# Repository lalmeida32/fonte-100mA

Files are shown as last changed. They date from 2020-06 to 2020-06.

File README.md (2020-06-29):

# Projeto: Fonte-100mA — TRABALHO 01

### Grupo 19, Integrantes:

* Adrio O. Alves (*11796830*)
* Eduardo V. B. Rossi (*10716887*)
* Felipi Y. Santos (*11917292*)
* Lucas F. de Almeida (*1162063*)

**Docente**: Eduardo do Valle Simões
**Curso**: SSC0180 - Eletrônica para Computação

**Bacharelado em Ciências da Computação — 2020**
**Instituto de Ciências Matemáticas e de Computação**
**Universidade de São Paulo**

---

# Introdução

	O projeto de trabalho 1 tem como objetivo a construção de uma fonte de alimentação genérica que precisa  fornecer corrente de até 100mA (*miliampères*) e uma tensão entre 3V e 12V. O projeto conta com um diagrama contendo os componentes eletrônicos escolhidos para construção da fonte, juntamente com o preço de cada um. Além disso, o projeto da fonte foi modelado em duas ferramentas de construção de circuitos: Falstad e EAGLE, e também um vídeo apresentando uma visão geral.

 # O repositório

* **estudo-do-projeto**

  * *Estudos.md*: Esse markdown dá informações do que cada componente eletrônico usado na fonte é, como ele é usado na fonte, isto é, seu papel.

  * **imagens**: fotos de peças/dependência do Estudos.md

  * *Dimensionamento.md*: relação de gastos e links para cada componente

* **arquivos-circuitos**

  * **FONTE**: arquivos do projeto no Eagle (contém esquemático e PCB)
  * *circuit-20200628-2337.circuitjs.txt*: um export do circuito feito no Falstad.
  * **EAGLE:** diretório contendo os arquivos do projeto no EAGLE
  * *eagle.jpg*: um export do projeto esquemático no EAGLE
  * *pcb.png*: um export do projeto em PCB no EAGLE
  * *circuito.png*: foto do circuito no falstad

# Diagrama da Fonte

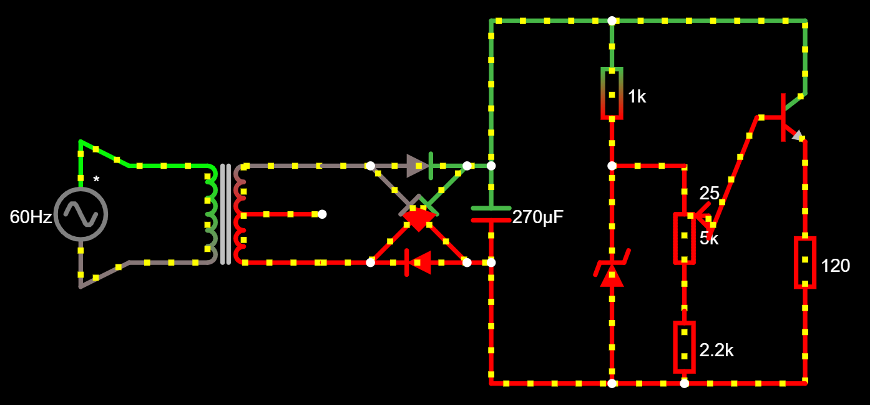
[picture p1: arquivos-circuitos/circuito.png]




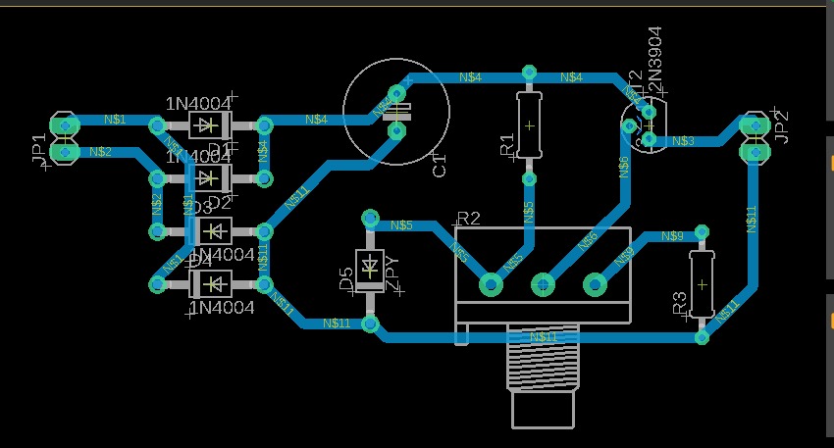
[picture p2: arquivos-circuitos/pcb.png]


# Relação componente/valores

**Obs**.: Desconsideramos o frete pois os preços de entrega encontram-se mais elevados durante o período da Pandemia (COVID-19). 

| Componente | Links | Quantidade | Preço resultante |
| --- | --- | --- | --- |
| **Transformador** 10+10 bivolt 800mA | https://produto.mercadolivre.com.br/MLB-1304934993-transformador-trafo-1010v-800ma-bivolt-eletrnica-_JM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 | x1 | R$ 30,00 |
| **Diodos da ponte retificadora** (1n4007) | https://www.robocore.net/loja/itens-eletronicos/diodo-1n4007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 | x4 | R$ 0,18 x 4 =  0,72 |
| **Capacitor** eletrolítico 270uF / 50V | https://produto.mercadolivre.com.br/MLB-1539705638-cap-eletrolitico-270uf-50v-kit-c-50-pcs-_JM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 | x1 | R$ 15,50 |
| **Diodo Zener** (BZX55C 13V/0,5W) | https://www.baudaeletronica.com.br/diodo-zener-bzx55c-13v-0-5w.html | x1 | R$ 0,09 |
| **Transistor NPN** (BC337) | https://www.robocore.net/loja/itens-eletronicos/transistor-npn-bc337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 | x1 | R$ 1,20 |
| **Resistor** (1kΩ) | https://www.robocore.net/loja/itens-eletronicos/resistor-1k-pacote-com-10-unidades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 | x1 | R$ 0,75 |
| **Resistor** (2.2kΩ) | https://www.eletroinfocia.com.br/resistor-1-4w-2k2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 | x1 | R$ 0,10 |
| **Potenciômetro** | https://www.engetronic-sc.com.br/produtos/ver/321/potenciometro-linear-5k-l15---eixo-estriado-tracking-google-shopping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 | x1 | R$ 1,35 |
| **TOTAL:** | | 11 | R$ 49,72 |

# Sobre os componentes não encontrados no EAGLE

	Como o EAGLE não possui todos os componentes que foram utilizados na fonte, tivemos de utilizar componentes com funcionalidade e dimensões iguais no lugar.

# Links

* Vídeo explicativo da fonte: https://youtu.be/iQQ3Y2TPxfM
* Falstad (cópia em arquivos-circuitos): https://tinyurl.com/y8z7htxh
* Eagle (esquemático): https://imgur.com/a/H5OCaSa
* Eagle (PCB): https://imgur.com/a/zWWUykP

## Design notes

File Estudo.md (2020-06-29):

# Estudo do Projeto

Fonte de 100mA

## Introdução

Neste documento se encontram as informações adquiridas para a montagem da fonte.

## Componentes

### Resistor

O resistor é um dispositivo elétrico que consome corrente elétrica. É utilizado principalmente para limitar a corrente elétrica em um circuito e para converter energia elétrica em energia térmica.

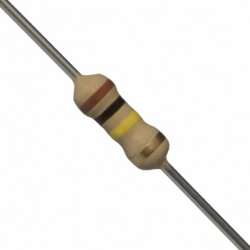
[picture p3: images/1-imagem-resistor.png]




Uma equação importante ao trabalhar com resistores é U = R ∙ i (Primeira Lei de Ohm), em que U é a diferença de potencial (em Volts), R é a resistência (em Ohms) e i é a corrente elétrica (em Amperes). A corrente no circuito varia de acordo com a resistência e a tensão.

    Primeira Lei de Ohm: U = R ∙ i

Outra equação importante para entender a grandeza “resistência elétrica”, é a Segunda Lei de Ohm. Na verdade, até um fio apresenta resistência, mas em circuitos simples não é necessário considerá-la.

    Segunda Lei de Ohm: R = (ρ ∙ L)/A

Nesse caso, ρ é uma constante associada ao material, (resistividade do material) L é o comprimento do fio e A é a área da seção transversal do fio.

Resistores combinados em série e em paralelo podem ser substituídos por um resistor equivalente. Caso os resistores sejam ligados em série, a nova resistência será igual à soma das resistências. Em paralelo, o inverso da nova resistência será igual à soma do inverso das resistências.

    Associação em série: Req = R1 + R2 + ⋯

    Associação em paralelo: 1/Req = 1/R1 + 1/R2 + ⋯

É importante notar o que acontece com a tensão e a corrente em circuitos elétricos em série e em paralelo.

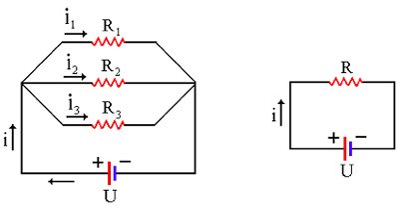
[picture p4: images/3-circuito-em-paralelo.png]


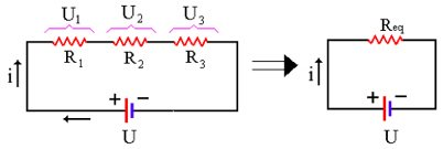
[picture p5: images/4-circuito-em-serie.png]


O circuito em paralelo divide a corrente (nesse caso, i1 + i2 + i3 = i), mas a tensão é a mesma em todos os resistores. Já no circuito em série, a tensão que é dividida (com U1 + U2 + U3 = U), sendo que a corrente que passa por cada um dos resistores é a mesma. O que descreve isso mais formalmente são as Leis de Kirchhoff.

Por esse motivo, para medir tensão, colocamos o voltímetro em paralelo, e para medir corrente, colocamos o amperímetro em série com o circuito.

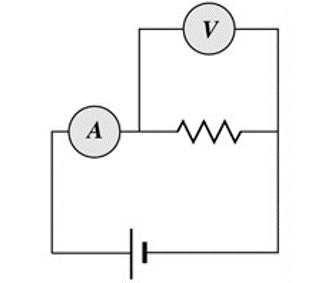
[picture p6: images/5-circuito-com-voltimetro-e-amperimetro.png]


Além disso, cada resistor consome energia de acordo com o tempo. Para medir isso, basta usar a potência, em watts. (1W = 1 J/s)

    Potência no resistor: P = U ∙ i

Para identificar quanto vale a resistência de um resistor segundo as faixas de cores que estão nele, basta utilizar a seguinte tabela:

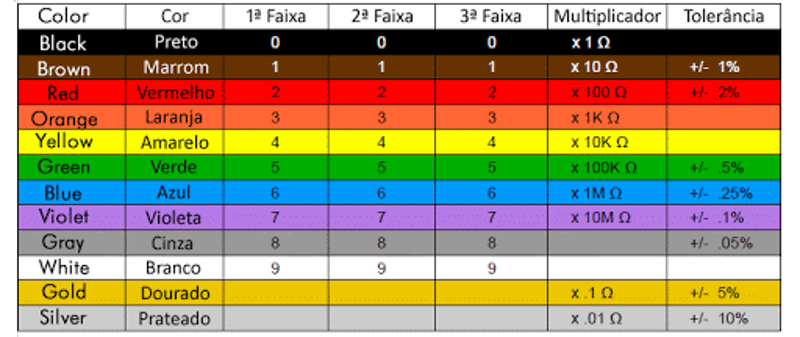
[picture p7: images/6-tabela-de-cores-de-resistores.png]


### Capacitor

O capacitor é um componente que armazena cargas elétricas.

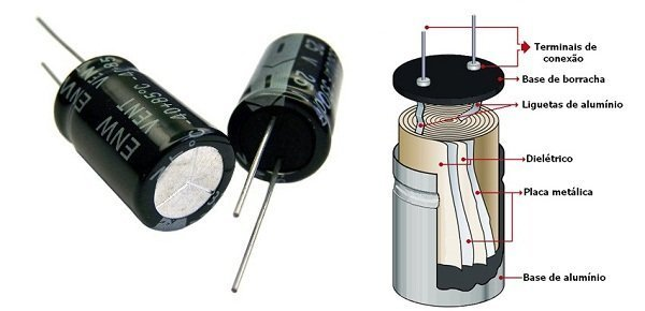
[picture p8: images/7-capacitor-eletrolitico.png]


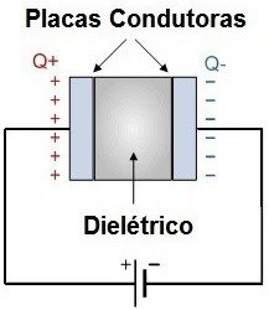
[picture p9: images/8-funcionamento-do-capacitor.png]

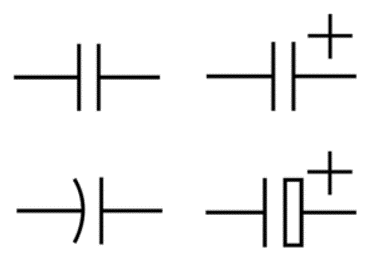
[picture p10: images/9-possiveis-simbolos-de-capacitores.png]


*Observação: Alguns tipos de capacitores são polarizados e outros não*

Em um capacitor, há um material isolante elétrico entre duas placas condutoras. Ao ligar o capacitor em um gerador de tensão, os elétrons se acumularão em uma das placas, gerando uma diferença de potencial entre seus terminais.

Em determinado momento, a diferença de potencial no capacitor será quase igual à diferença de potencial no gerador de tensão, e então o capacitor será carregado muito lentamente.

Uma vez carregado, o capacitor serve de gerador de tensão e pode ser descarregado em um circuito.

Para medir a capacidade de armazenamento de um capacitor, utiliza-se a grandeza escalar “capacitância”. Quanto maior a capacitância, maior a capacidade de armazenamento. A capacitância C (em farads) está associada com a área das placas condutoras S (em metros quadrados), a distância entre elas d (em metros) e a constante dielétrica ε (em farads por metro) pela seguinte relação:

    C = ε S/d

Há também outro jeito de calcular a capacitância:

    C = q/ΔV

Em que C é a capacitância, em farads, q é a carga elétrica armazenada, em coulombs, e V é a diferença de potencial, em volts.

Sendo assim, temos que 1F = 1C/V.

Ao associar capacitores em série ou paralelo, podemos obter um capacitor com capacitância equivalente aplicando as seguintes fórmulas:

    Associação em série: 1/Ceq = 1/C1 + 1/C2 + ⋯

    Associação em paralelo: Ceq = C1 + C2 + ⋯

É importante também estudar o circuito RC. (Resistor e Capacitor)

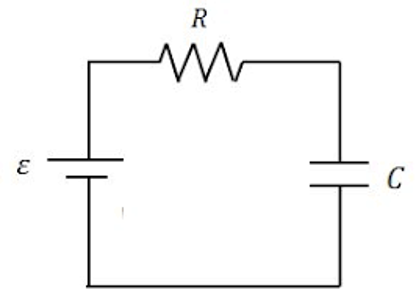
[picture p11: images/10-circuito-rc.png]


Nesse circuito, o capacitor levará um tempo para ser carregado. Estes gráficos descrevem o que acontece no circuito RC.

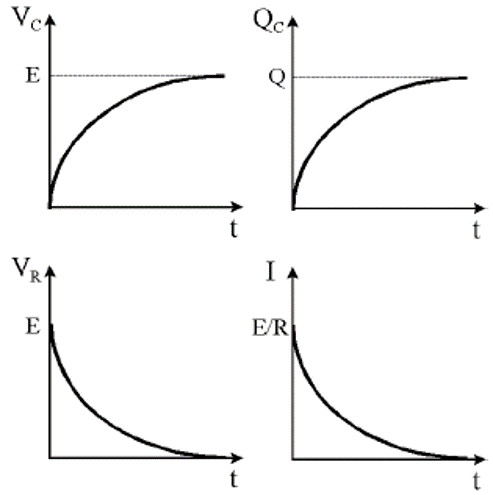
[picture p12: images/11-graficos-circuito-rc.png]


Vc é a tensão no capacitor, Qc é a carga no capacitor, Vr é a tensão no resistor e I é a corrente no circuito. (o resistor e o capacitor estão em série e a mesma corrente passa por eles)

Nesse circuito, o tempo que leva para o capacitor carregar é diretamente proporcional à capacitância e à resistência. (quanto maior a resistência/capacitância, maior o tempo que leva)

A tensão elétrica no gerador de tensão define qual será a tensão máxima que o capacitor poderá atingir.

*Observação: Ao descarregar o capacitor em um resistor, os gráficos são semelhantes, mas a tensão e a carga no capacitor diminuem ao invés de aumentar.*

### Diodo

O diodo é um componente que só deixa passar corrente em um sentido.

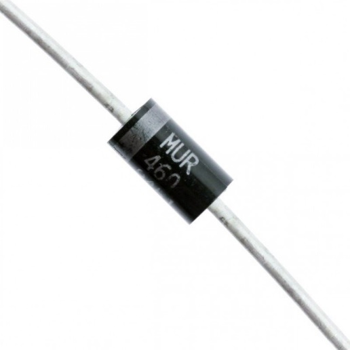
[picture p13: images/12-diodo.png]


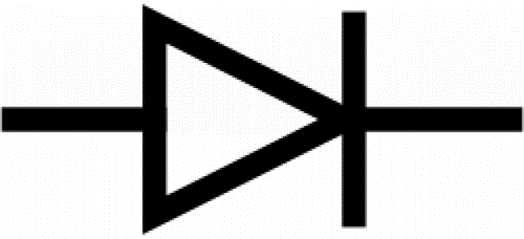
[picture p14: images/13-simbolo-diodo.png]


O sentido que o diodo permite a corrente passar é o sentido da seta em seu símbolo.

Em um diodo real, se determina esse sentido através da faixa cinza que há nele. Chamamos o terminal mais próximo da faixa cinza de cátodo (negativo) e o terminal mais longe de ânodo (positivo).



Caso o diodo seja ligado diretamente (negativo no cátodo e positivo no ânodo), a corrente fluirá como se o diodo fosse uma chave fechada. Caso ele seja conectado inversamente (positivo no cátodo e negativo no ânodo), o diodo se comportará como uma chave aberta.

Na realidade, o diodo conectado diretamente funciona como chave fechada a partir de determinada tensão. Para entender melhor como isso funciona, veja a figura abaixo.

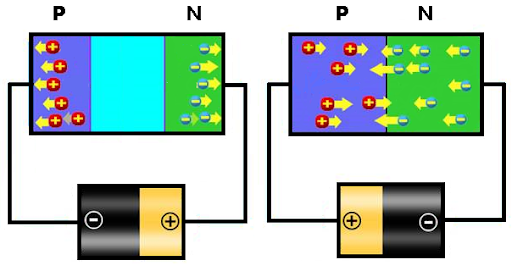
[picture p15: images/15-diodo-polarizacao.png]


A região do meio de um diodo é chamada de barreira de potencial (ou camada de depleção). Ela separa o cátodo e o ânodo de um diodo. Quando um diodo é ligado inversamente, essa barreira aumenta pois as cargas positivas são atraídas para o polo negativo da pilha e as cargas negativas, para o polo positivo da pilha. Já se o diodo é ligado diretamente, ao aumentar a tensão, a barreira de potencial fica cada vez menor até que, em certo momento, ela desaparece e o diodo passa a funcionar como um fio.

Dessa forma, o diodo causa uma queda de tensão no circuito. No exemplo abaixo, apesar da fonte de tensão fornecer 10V, a tensão no resistor será em torno de 9,2V, já que se trata de um diodo de silício (o material influencia na tensão necessária para "quebrar" a barreira de potencial).

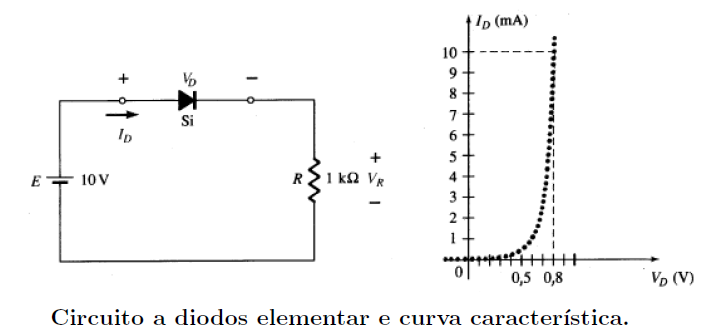
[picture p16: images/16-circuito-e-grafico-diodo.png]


*Observação: é comum dizer que o diodo de silício causa uma queda de tensão de aproximadamente 0,7V. Aqui neste documento está escrito como se causasse 0,8V por conta do gráfico presente na imagem*

O significado da sigla LED é *Light Emissor Diode*, ou seja, se trata de um diodo também. LEDs costumam causar uma queda de tensão maior que 0,7V, geralmente multímetros possuem uma função para calcular essa tensão.

Há coisas como corrente e tensão máximas que um diodo pode suportar. Isso depende do diodo e esse tipo de informação pode ser encontrada no datasheet.

### Diodo Zener

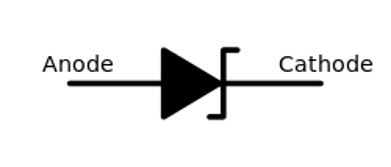
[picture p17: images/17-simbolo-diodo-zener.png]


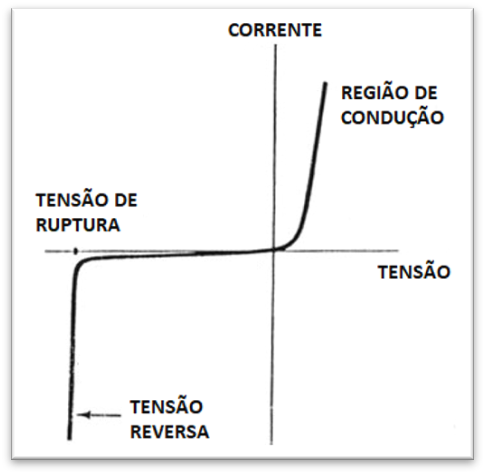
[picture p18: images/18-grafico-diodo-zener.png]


O diodo zener é como um diodo normal, porem a partir de certa tensão ele passa a ser um curto circuito, essa é a TENSÃO ZENER. Se a tensão no diodo zener for menor que a tensão zener ele não conduz, assim como os diodos convencionais. Se a tensão for maior que a tensão zener, o diodo zener mesmo estando contrario ao circuito vai conduzir.

    Uin < |Vzener|, Uout = Uin

    Uin > |Vzener|, Uout = Vzener

O diodo zener tem uma corrente máxima suportável, e isso é delimitado de acordo com a potencia do componente, caso a potência do circuito seja ultrapassada, o diodo pode se danificar.

    Izmax = Pz/Vz

    Izmin = Izmax ∙ 0,10

    Rzmin = (Vcc - Vz)/Izmax

    Rzmax = (Vcc - Vz)/Izmin

*Rz: Resistor limitador de corrente*

Esse diodo é muito bom para retificar a onda de tensão, principalmente quando se deseja estabelecer uma tensão continua. Nesse ciruito, o zener pode ser útil, porque ele controla a tensão, cortando-a em apenas um valor. Isso acontece porque ele mantém o valor de tensão máxima em seus terminais caso esteja conduzindo reversamente.

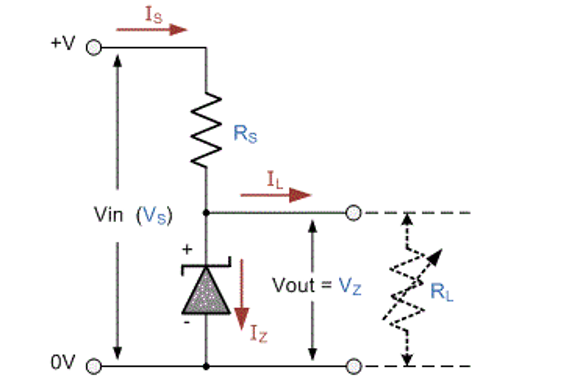
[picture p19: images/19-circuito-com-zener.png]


Esse é um simples circuito limitador de tensão usando zener. Vout sempre será Vz (tensão zener) na carga sempre que Vin > Vz, já que o diodo zener irá limitar.

### Transformadores
O transformador modifica os níveis de tensão e corrente elétrica, mantendo a potência constante.
Como a potência se mantém constante, ao usarmos o transformador para diminuir a tensão, a corrente do nosso circuito vai aumentar.

    P1 = P2 <=> V1 . I1 = V2 . I2

Estrutura:

Enrolamento:  O enrolamento de um transformador é formado de várias bobinas (os transformadores mais comuns usam duas) que em geral são feitas de cobre. Quando a corrente passa pela bobina forma um campo magnético que produz uma tensão elétrica nas extremidades desse enrolamento. A alteração na corrente presente na bobina do circuito primário altera o fluxo magnético nesse circuito e também na bobina do circuito secundário.

Núcleo: responsável por transferir a corrente do enrolamento primário para o enrolamento secundário. A mudança no fluxo magnético na bobina secundária induz uma tensão elétrica na bobina secundária

O transformador altera a tensão através de duas bobinas, seguindo uma proporção de uma bobina para a outra. Ex: se tivermos 100 voltas em uma e 10 voltas na outra, a tensão será transformada na proporção de 10 para 1, ou seja, se tivermos 100V na entrada, teremos 10V na saída.

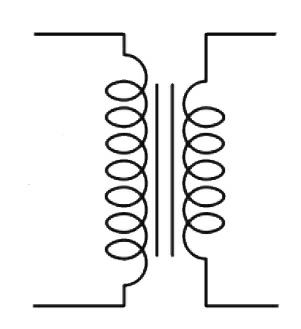
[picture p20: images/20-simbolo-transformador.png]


*Observação: damos o nome de primário o enrolamento da esquerda e secundário o da direita*

Os valores analisados em um transformador são relativos à tensão eficaz. Por exemplo, a tensão eficaz V1 é transformada na tensão eficaz V2.
Para calcular a tensão eficaz, basta dividir a tensão de pico por √2.

As tomadas residenciais geralmente fornecem de 110V a 127V ou de 220V a 254V de tensão eficaz.

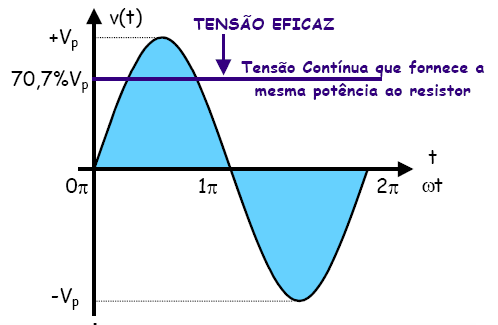
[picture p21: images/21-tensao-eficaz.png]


Há transformadores com derivação central. Segue na imagem abaixo um exemplo de um.

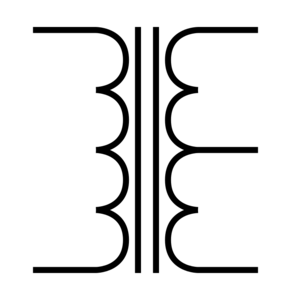
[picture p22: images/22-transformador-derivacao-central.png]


Se o transformador for 12V + 12V, por exemplo, significa que entre um dos terminais laterais e o terminal do meio, há 12V. Dessa forma, ao medir a tensão entre os terminais laterais, o resultado deve ser 24V (tensão eficaz)

Além disso, transformadores reais possuem rendimento, pois dissipam calor. Por exemplo, um transformador com 90% de rendimento, significa que a potência no secundário é 90% da potência no primário. Transformadores bons possuem mais que 90% de rendimento.

Geralmente transformadores são projetados também com um fio a mais no primário para tornar possível a escolha entre 127V ou 220V.

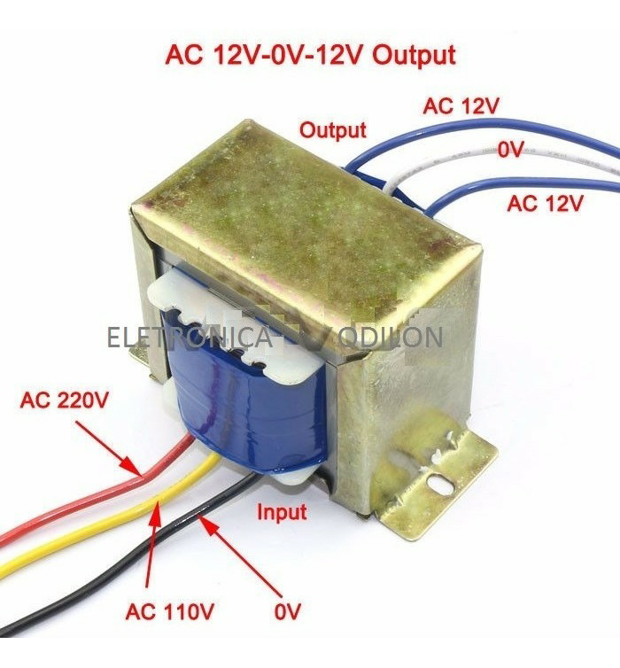
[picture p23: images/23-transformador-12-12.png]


Este é um exemplo de transformador real. Nesse caso, o fio de 127V está próximo ao meio da bobina, como na derivação central, mas não se encontra exatamente no meio.

Uma chave seletora pode ajudar na passagem de 127V para 220V e vice-versa.

### Potenciômetro

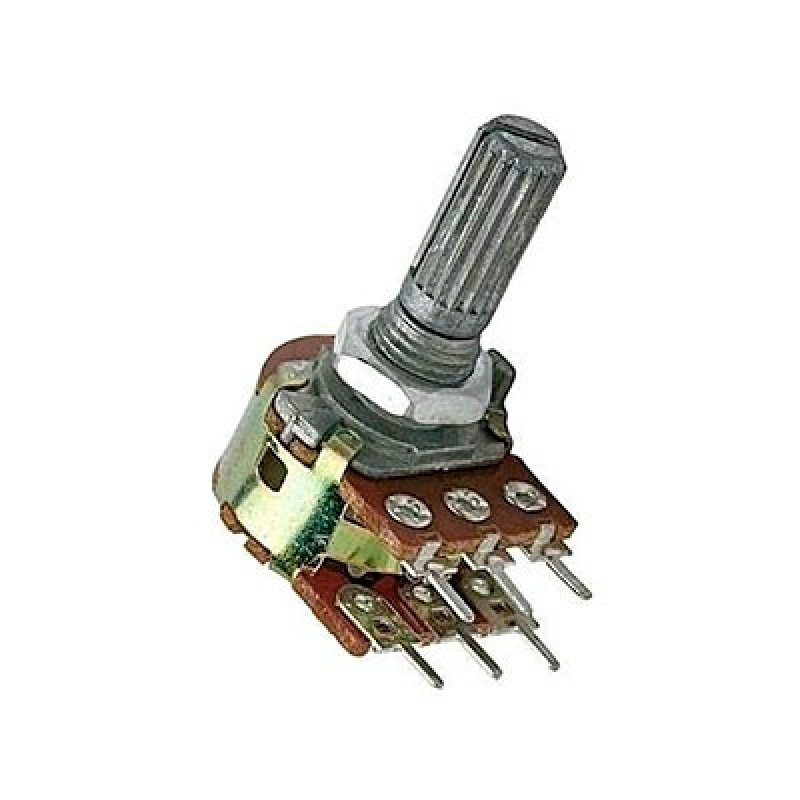
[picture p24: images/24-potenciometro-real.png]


Um potenciômetro é como se fosse um conjunto de duas resistências em que é possível regular manualmente a proporção em que cada uma delas vai receber da resistência total. Segue duas imagens para melhor entendimento.

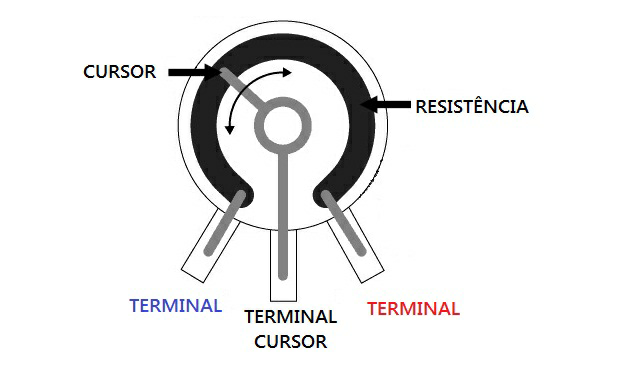
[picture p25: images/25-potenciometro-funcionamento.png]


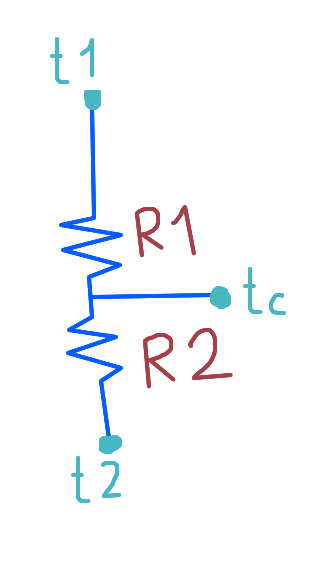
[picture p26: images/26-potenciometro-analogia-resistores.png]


O cursor pode ser ajustado manualmente. Ele determina qual porção da resistência total do potenciômetro o R1 e o R2 vão ter. Note que R1 + R2 deve ser igual à resistência do potenciômetro.

Note também que tc é o terminal do cursor, enquanto t1 e t2 são os terminais de R1 e de R2, respectivamente.

Suponha um potenciômetro de 100Ω. R1 + R2 sempre será 100Ω, mas o valor de R1 e de R2 pode ser regulado pelo cursor. Por exemplo, ao aproximar o cursor de t1, R1 se aproxima de 0Ω e R2 se aproxima de 100Ω. Ao aproximar de t2, R2 se aproxima de 0Ω enquanto R1 se aproxima de 100Ω. Há infinitos valores intermediários, como R1 = 67,3Ω e R2 = 32,7Ω.

Potenciômetros podem ser encontrados, por exemplo, em caixas de som no regulador de volume.

### Transistor NPN

O transistor TBJ NPN, é um componente que funciona como uma válvula/interruptores de tensão em um circuito, ou também, ele funciona ou barrando, ou amplificando a corrente elétrica. Seu funcionamento depende de 3 terminais, base, coletor e emissor. A corrente a ser controlada é a Ic := corrente no coletor, ou seja, é a corrente que passa do coletor ao emissor.



1) Base: é o terminal controlador, ele que determina se haverá ou não passagem de corrente entre o coletor e o emissor.

2) Coletor: entrada do transistor, ela que inicialmente controla a tensão e corrente no emissor.

3) Emissor: saída do transistor.



Definição de Variáveis:

a) Vc: tensão no coletor;

b) Vb: tensão na base;

c) Vbe: tensão entre a base e o emissor, normalmente está entre 0,7V;

d) Ve: tensão no emissor;

Ve(max) = Vb – Vbe

Inicialmente, Ve = Vc; Mas caso, Vc < Vb: Ve = Vb – Vbe.

e) Vce = Vc – Ve;

f) Ie = Ve / Re;

g) Ic = Ie * a = Ie * ganho/ganho+1		ou	Ic = Ib * ganho

h) Ib = Ic / ganho		ou	Ib = (Vb – Vc ) / Rb

## Seções da fonte

### Papel do Transformador

No projeto da fonte vamos precisar de um transformador para reduzir a tensão da tomada, 110V ou 220V, para uma tensão entre 3V - 12V.

O papel do transformador na fonte é reduzir a tensão da entrada para que o circuito não precise trabalhar com tensões muito elevadas que podem danificar componentes ou exigir componentes mais caros.

### Papel da Ponte Retificadora



A ponte retificadora, uma associação de 4 diodos, serve para transformar a corrente alternada em uma corrente contínua pulsante (a polaridade se mantém, mas a tensão ainda varia com o tempo). A propriedade dos diodos que é utilizada na ponte retificadora é a de não conduzir quando está polarizado inversamente.

Segue uma análise da ponte retificadora em uma carga.





Note que tanto faz se o positivo está em cima e o negativo em baixo, ou o positivo em baixo e o negativo em cima. A corrente fluirá pela carga R1 no mesmo sentido: cima para baixo.



A corrente alternada passa pela ponte retificadora e se torna corrente contínua pulsante.

### Papel do Capacitor

O papel do capacitor na fonte é proporcionar o *ripple*. Como agora a corrente é contínua e pulsante, o capacitor armazena a carga e descarrega lentamente enquanto a tensão estaria abaixo da tensão que o capacitor obteve. Segue um gráfico para entender melhor o que seria o *ripple*.



No começo do primeiro ciclo da onda, o capacitor estará sendo carregado até a tensão de pico. Quando a tensão cai, o capacitor libera a carga que foi armazenada aos poucos, até que a tensão de do segundo ciclo da onda seja maior que a tensão no capacitor, que irá carregá-lo novamente. Isso se segue repetidas vezes.

Com o *ripple*, a tensão está mais estável: ainda varia, mas muito menos.

### Papel do Circuito Regulador

O circuito regulador vai regular a tensão na carga de acordo com a posição do cursor do potenciômetro.

Esse circuito será explicado por partes.

#### Divisor de tensão

O divisor de tensão nada mais é que uma análise da tensão em um resistor de um circuito de vários resistores associados em série.

O caso mais comum é o de dois resistores conectados em série. Nesse caso, a fórmula para calcular a tensão no resistor R2 é a seguinte:

    (V ∙ R2) / (R1 + R2)

Em que V é a tensão da alimentação.

A fórmula para R1 é análoga, e para divisores de tensão com mais resistores, basta considerar como R1 (ou R2) o resistor equivalente à todos os resistores exceto aquele cuja tensão está sendo analisada.

O divisor de tensão é uma consequência direta da lei das malhas de *Kirchhoff*.

#### Divisor de tensão combinado com diodo zener



Basicamente, o circuito do divisor de tensão junto com o zener é este.

Funciona da seguinte forma: se o Vout calculado pelo divisor de tensão em Rl for menos que o Vzener, então a tensão em Rl (e no zener) será Vout e a tensão em Rs será Vin - Vout.

Mas se Vout for maior que Vzener, a tensão em Rl e no zener será Vzener, e a tensão em Rs será Vin - Vzener.

Observe que o diodo zener está polarizado inversamente. Apenas dessa forma o circuito funcionará do modo esperado, pois caso contrário, seria como um diodo comum.

#### Potenciômetro, carga e transistor



A região no lado esquerdo do circuito é a do divisor de tensão combinado com o diodo zener.

Considerando apenas o divisor de tensão, o potenciômetro (de resistência Rp) pode ser considerado um resistor, conectado em série com R2.

Dessa forma, aplicando a fórmula do divisor de tensão e da resistência equivalente para resistores em série, temos:

    Vo = (V ∙ (R2 + Rp)) / (R1 + R2 + Rp)

Se Vo for maior que Vzener (o objetivo), o Vzener irá agir e, ao invés da tensão Vo passar pelo conjunto Rp e R2, será a tensão Vzener que passará.

O transistor NPN tem 2 funções principalmente: a primeira, utilizar uma corrente baixa para controlar a corrente mais alta que passará na carga (de resistência Rl); a segunda, "isolar" a carga para que ele não interfira no cálculo do divisor de tensão e altere a tensão no diodo zener.

A tensão na carga pode ser calculada como se ela estivesse em paralelo com o conjunto do resistor R2 e o potenciômetro (até onde o cursor está posicionado), considerando a queda de tensão de aproximadamente 0,7V que o transistor provoca.

É dessa forma que a tensão na carga pode ser regulada: em um dos extremos do cursor do potenciômetro, a tensão que passará pela carga será Vzener - 0,7V; no outro extremo, a tensão que passará pela carga será Vr2 (a tensão em R2) - 0,7V.

## Dimensionamento

### Link para o Circuito

#### tinyurl.com/y8z7htxh

### Transformador

Transformador utilizado: 10+10 bivolt 800mA. Usaremos os terminais das pontas a fim de obter 20V

https://produto.mercadolivre.com.br/MLB-1304934993-transformador-trafo-1010v-800ma-bivolt-eletrnica-_JM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

Preço: 30 reais

Dados no circuito: a tensão máxima no secundário será de aproximadamente 28,28V.

Por que usaremos esse transformador: Atende às necessidades, já que a tensão fornecida será maior que 13V com folga, é barato e não será danificado pela corrente que passará por ele.

### Diodos para ponte retificadora

Diodos utilizados: 1n4007

https://www.robocore.net/loja/itens-eletronicos/diodo-1n4007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

Preço: 18 centavos a unidade

Dados no circuito: provocará uma queda de tensão de 0,7V cada um. A tensão máxima que antes era 28,28V, será de 26,88V depois de passar pela ponte retificadora.

Por que usaremos esse diodo: pois ele é comum, barato e suporta alta tensão (um 1n4001 seria suficiente, mas na internet foi mais fácil encontrar 1n4007).

### Capacitor

Capacitor utilizado: eletrolítico 270uF / 50V

https://produto.mercadolivre.com.br/MLB-1539705638-cap-eletrolitico-270uf-50v-kit-c-50-pcs-_JM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

Preço: 31 centavos a unidade

Dados no circuito: proporcionará um ripple de 23,9V a 26,88V

Por que usaremos esse capacitor: é comum, barato, torna a variação de tensão no ripple baixa e suporta até 50V.

### Diodo Zener

Zener utilizado: BZX55C [13V / 0,5W]

https://www.baudaeletronica.com.br/diodo-zener-bzx55c-13v-0-5w.html

Preço: 9 centavos

Dados no circuito: a corrente que passará por ele será de 8,2 mA a 10,9 mA, aproximadamente (a variação ocorre por conta do *ripple*). Para que o diodo funcione corretamente, é necessário que passe ao menos 3,8mA por ele (e no máximo, 38mA). Dessa forma, ele está sendo alimentado de maneira correta: com folga e sem danificá-lo.

Por que usaremos esse zener: é comum, barato, e como o circuito será regulado a no máximo 12V e há uma queda de tensão entre base e emissor no transistor, 13V é o ideal.

### Transistor NPN

Transistor NPN utilizado: BC337

https://www.robocore.net/loja/itens-eletronicos/transistor-npn-bc337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

Preço: 24 centavos a unidade

Dados no circuito: os dados irão depender de como o potenciômetro será regulado e da resistência na carga

Considerando uma carga de 120 ohm e o potenciômetro no estado em que o máximo de tensão é fornecida à carga, como há uma queda de tensão de 0,7V, a carga receberá em torno de 12,3V no máximo, então a corrente no emissor será de 102,5 mA

    Considerando o ganho mínimo de 100, a corrente na base será 1,01mA, e no coletor será 101,5mA

    Considerando agora o ganho máximo de 630, a corrente na base será 0,16mA, e no coletor será 102,34mA

    A tensão entre base e coletor será entre 10,9V e 13,88V.

Quando o potenciômetro estiver no estado em que o mínimo de tensão é fornecida à carga, a corrente será desprezível e a tensão entre base e coletor será entre 20,2V e 23,18V.

Por que usaremos esse transistor: é comum, barato e suporta a tensão e corrente necessárias no circuito

### Resistores e potenciômetro no regulador

Resistores utilizados: 1k e 2.2k

Potenciômetro utilizado: 5k

https://www.engetronic-sc.com.br/produtos/ver/321/potenciometro-linear-5k-l15---eixo-estriado-tracking-google-shopping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

https://www.robocore.net/loja/itens-eletronicos/resistor-1k-pacote-com-10-unidades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

https://www.eletroinfocia.com.br/resistor-1-4w-2k2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

Preço: por volta de 2 reais e 10 centavos

Dados no circuito:

Tomando Rp = 5k, R2 = 2.2k e R1 = 1k e considerando o caso em que o potenciômetro está fornecendo o máximo de tensão à carga.

Primeiro, considerando o menor valor para Vin possível (23,9V):

    Corrente no resistor R1: 10,9mA

    Corrente no resistor R2: 1,8mA

    Vin * (R2 + Rp)/(R2 + Rp + R1) = 23,9 * 7200/8200 = 21V > 13V

Agora, o maior valor possível (26,88V):

    Corrente no resistor R1: 13,9mA

    Corrente no resistor R2: 1,8mA

    26,88 * 7200/8200 > 21V > 13V

Por que usaremos esses resistores e esse potenciômetro: são fáceis de encontrar (valores comerciais), baratos, suportam a corrente que passará por eles com folga e atendem às necessidades do circuito.

## Eagle e PCB

### Esquemático



### PCB



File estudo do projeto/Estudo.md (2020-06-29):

# Estudo do Projeto

Fonte de 100mA

## Introdução

Neste documento se encontram as informações adquiridas para a montagem da fonte.

## Componentes

### Resistor

O resistor é um dispositivo elétrico que consome corrente elétrica. É utilizado principalmente para limitar a corrente elétrica em um circuito e para converter energia elétrica em energia térmica.





Uma equação importante ao trabalhar com resistores é U = R ∙ i (Primeira Lei de Ohm), em que U é a diferença de potencial (em Volts), R é a resistência (em Ohms) e i é a corrente elétrica (em Amperes). A corrente no circuito varia de acordo com a resistência e a tensão.

    Primeira Lei de Ohm: U = R ∙ i

Outra equação importante para entender a grandeza “resistência elétrica”, é a Segunda Lei de Ohm. Na verdade, até um fio apresenta resistência, mas em circuitos simples não é necessário considerá-la.

    Segunda Lei de Ohm: R = (ρ ∙ L)/A

Nesse caso, ρ é uma constante associada ao material, (resistividade do material) L é o comprimento do fio e A é a área da seção transversal do fio.

Resistores combinados em série e em paralelo podem ser substituídos por um resistor equivalente. Caso os resistores sejam ligados em série, a nova resistência será igual à soma das resistências. Em paralelo, o inverso da nova resistência será igual à soma do inverso das resistências.

    Associação em série: Req = R1 + R2 + ⋯

    Associação em paralelo: 1/Req = 1/R1 + 1/R2 + ⋯

É importante notar o que acontece com a tensão e a corrente em circuitos elétricos em série e em paralelo.





O circuito em paralelo divide a corrente (nesse caso, i1 + i2 + i3 = i), mas a tensão é a mesma em todos os resistores. Já no circuito em série, a tensão que é dividida (com U1 + U2 + U3 = U), sendo que a corrente que passa por cada um dos resistores é a mesma. O que descreve isso mais formalmente são as Leis de Kirchhoff.

Por esse motivo, para medir tensão, colocamos o voltímetro em paralelo, e para medir corrente, colocamos o amperímetro em série com o circuito.



Além disso, cada resistor consome energia de acordo com o tempo. Para medir isso, basta usar a potência, em watts. (1W = 1 J/s)

    Potência no resistor: P = U ∙ i

Para identificar quanto vale a resistência de um resistor segundo as faixas de cores que estão nele, basta utilizar a seguinte tabela:



### Capacitor

O capacitor é um componente que armazena cargas elétricas.






*Observação: Alguns tipos de capacitores são polarizados e outros não*

Em um capacitor, há um material isolante elétrico entre duas placas condutoras. Ao ligar o capacitor em um gerador de tensão, os elétrons se acumularão em uma das placas, gerando uma diferença de potencial entre seus terminais.

Em determinado momento, a diferença de potencial no capacitor será quase igual à diferença de potencial no gerador de tensão, e então o capacitor será carregado muito lentamente.

Uma vez carregado, o capacitor serve de gerador de tensão e pode ser descarregado em um circuito.

Para medir a capacidade de armazenamento de um capacitor, utiliza-se a grandeza escalar “capacitância”. Quanto maior a capacitância, maior a capacidade de armazenamento. A capacitância C (em farads) está associada com a área das placas condutoras S (em metros quadrados), a distância entre elas d (em metros) e a constante dielétrica ε (em farads por metro) pela seguinte relação:

    C = ε S/d

Há também outro jeito de calcular a capacitância:

    C = q/ΔV

Em que C é a capacitância, em farads, q é a carga elétrica armazenada, em coulombs, e V é a diferença de potencial, em volts.

Sendo assim, temos que 1F = 1C/V.

Ao associar capacitores em série ou paralelo, podemos obter um capacitor com capacitância equivalente aplicando as seguintes fórmulas:

    Associação em série: 1/Ceq = 1/C1 + 1/C2 + ⋯

    Associação em paralelo: Ceq = C1 + C2 + ⋯

É importante também estudar o circuito RC. (Resistor e Capacitor)



Nesse circuito, o capacitor levará um tempo para ser carregado. Estes gráficos descrevem o que acontece no circuito RC.



Vc é a tensão no capacitor, Qc é a carga no capacitor, Vr é a tensão no resistor e I é a corrente no circuito. (o resistor e o capacitor estão em série e a mesma corrente passa por eles)

Nesse circuito, o tempo que leva para o capacitor carregar é diretamente proporcional à capacitância e à resistência. (quanto maior a resistência/capacitância, maior o tempo que leva)

A tensão elétrica no gerador de tensão define qual será a tensão máxima que o capacitor poderá atingir.

*Observação: Ao descarregar o capacitor em um resistor, os gráficos são semelhantes, mas a tensão e a carga no capacitor diminuem ao invés de aumentar.*

### Diodo

O diodo é um componente que só deixa passar corrente em um sentido.





O sentido que o diodo permite a corrente passar é o sentido da seta em seu símbolo.

Em um diodo real, se determina esse sentido através da faixa cinza que há nele. Chamamos o terminal mais próximo da faixa cinza de cátodo (negativo) e o terminal mais longe de ânodo (positivo).



Caso o diodo seja ligado diretamente (negativo no cátodo e positivo no ânodo), a corrente fluirá como se o diodo fosse uma chave fechada. Caso ele seja conectado inversamente (positivo no cátodo e negativo no ânodo), o diodo se comportará como uma chave aberta.

Na realidade, o diodo conectado diretamente funciona como chave fechada a partir de determinada tensão. Para entender melhor como isso funciona, veja a figura abaixo.



A região do meio de um diodo é chamada de barreira de potencial (ou camada de depleção). Ela separa o cátodo e o ânodo de um diodo. Quando um diodo é ligado inversamente, essa barreira aumenta pois as cargas positivas são atraídas para o polo negativo da pilha e as cargas negativas, para o polo positivo da pilha. Já se o diodo é ligado diretamente, ao aumentar a tensão, a barreira de potencial fica cada vez menor até que, em certo momento, ela desaparece e o diodo passa a funcionar como um fio.

Dessa forma, o diodo causa uma queda de tensão no circuito. No exemplo abaixo, apesar da fonte de tensão fornecer 10V, a tensão no resistor será em torno de 9,2V, já que se trata de um diodo de silício (o material influencia na tensão necessária para "quebrar" a barreira de potencial).



*Observação: é comum dizer que o diodo de silício causa uma queda de tensão de aproximadamente 0,7V. Aqui neste documento está escrito como se causasse 0,8V por conta do gráfico presente na imagem*

O significado da sigla LED é *Light Emissor Diode*, ou seja, se trata de um diodo também. LEDs costumam causar uma queda de tensão maior que 0,7V, geralmente multímetros possuem uma função para calcular essa tensão.

Há coisas como corrente e tensão máximas que um diodo pode suportar. Isso depende do diodo e esse tipo de informação pode ser encontrada no datasheet.

### Diodo Zener





O diodo zener é como um diodo normal, porem a partir de certa tensão ele passa a ser um curto circuito, essa é a TENSÃO ZENER. Se a tensão no diodo zener for menor que a tensão zener ele não conduz, assim como os diodos convencionais. Se a tensão for maior que a tensão zener, o diodo zener mesmo estando contrario ao circuito vai conduzir.

    Uin < |Vzener|, Uout = Uin

    Uin > |Vzener|, Uout = Vzener

O diodo zener tem uma corrente máxima suportável, e isso é delimitado de acordo com a potencia do componente, caso a potência do circuito seja ultrapassada, o diodo pode se danificar.

    Izmax = Pz/Vz

    Izmin = Izmax ∙ 0,10

    Rzmin = (Vcc - Vz)/Izmax

    Rzmax = (Vcc - Vz)/Izmin

*Rz: Resistor limitador de corrente*

Esse diodo é muito bom para retificar a onda de tensão, principalmente quando se deseja estabelecer uma tensão continua. Nesse ciruito, o zener pode ser útil, porque ele controla a tensão, cortando-a em apenas um valor. Isso acontece porque ele mantém o valor de tensão máxima em seus terminais caso esteja conduzindo reversamente.



Esse é um simples circuito limitador de tensão usando zener. Vout sempre será Vz (tensão zener) na carga sempre que Vin > Vz, já que o diodo zener irá limitar.

### Transformadores
O transformador modifica os níveis de tensão e corrente elétrica, mantendo a potência constante.
Como a potência se mantém constante, ao usarmos o transformador para diminuir a tensão, a corrente do nosso circuito vai aumentar.

    P1 = P2 <=> V1 . I1 = V2 . I2

Estrutura:

Enrolamento:  O enrolamento de um transformador é formado de várias bobinas (os transformadores mais comuns usam duas) que em geral são feitas de cobre. Quando a corrente passa pela bobina forma um campo magnético que produz uma tensão elétrica nas extremidades desse enrolamento. A alteração na corrente presente na bobina do circuito primário altera o fluxo magnético nesse circuito e também na bobina do circuito secundário.

Núcleo: responsável por transferir a corrente do enrolamento primário para o enrolamento secundário. A mudança no fluxo magnético na bobina secundária induz uma tensão elétrica na bobina secundária

O transformador altera a tensão através de duas bobinas, seguindo uma proporção de uma bobina para a outra. Ex: se tivermos 100 voltas em uma e 10 voltas na outra, a tensão será transformada na proporção de 10 para 1, ou seja, se tivermos 100V na entrada, teremos 10V na saída.



*Observação: damos o nome de primário o enrolamento da esquerda e secundário o da direita*

Os valores analisados em um transformador são relativos à tensão eficaz. Por exemplo, a tensão eficaz V1 é transformada na tensão eficaz V2.
Para calcular a tensão eficaz, basta dividir a tensão de pico por √2.

As tomadas residenciais geralmente fornecem de 110V a 127V ou de 220V a 254V de tensão eficaz.



Há transformadores com derivação central. Segue na imagem abaixo um exemplo de um.



Se o transformador for 12V + 12V, por exemplo, significa que entre um dos terminais laterais e o terminal do meio, há 12V. Dessa forma, ao medir a tensão entre os terminais laterais, o resultado deve ser 24V (tensão eficaz)

Além disso, transformadores reais possuem rendimento, pois dissipam calor. Por exemplo, um transformador com 90% de rendimento, significa que a potência no secundário é 90% da potência no primário. Transformadores bons possuem mais que 90% de rendimento.

Geralmente transformadores são projetados também com um fio a mais no primário para tornar possível a escolha entre 127V ou 220V.



Este é um exemplo de transformador real. Nesse caso, o fio de 127V está próximo ao meio da bobina, como na derivação central, mas não se encontra exatamente no meio.

Uma chave seletora pode ajudar na passagem de 127V para 220V e vice-versa.

### Potenciômetro



Um potenciômetro é como se fosse um conjunto de duas resistências em que é possível regular manualmente a proporção em que cada uma delas vai receber da resistência total. Segue duas imagens para melhor entendimento.





O cursor pode ser ajustado manualmente. Ele determina qual porção da resistência total do potenciômetro o R1 e o R2 vão ter. Note que R1 + R2 deve ser igual à resistência do potenciômetro.

Note também que tc é o terminal do cursor, enquanto t1 e t2 são os terminais de R1 e de R2, respectivamente.

Suponha um potenciômetro de 100Ω. R1 + R2 sempre será 100Ω, mas o valor de R1 e de R2 pode ser regulado pelo cursor. Por exemplo, ao aproximar o cursor de t1, R1 se aproxima de 0Ω e R2 se aproxima de 100Ω. Ao aproximar de t2, R2 se aproxima de 0Ω enquanto R1 se aproxima de 100Ω. Há infinitos valores intermediários, como R1 = 67,3Ω e R2 = 32,7Ω.

Potenciômetros podem ser encontrados, por exemplo, em caixas de som no regulador de volume.

### Transistor NPN

O transistor TBJ NPN, é um componente que funciona como uma válvula/interruptores de tensão em um circuito, ou também, ele funciona ou barrando, ou amplificando a corrente elétrica. Seu funcionamento depende de 3 terminais, base, coletor e emissor. A corrente a ser controlada é a Ic := corrente no coletor, ou seja, é a corrente que passa do coletor ao emissor.



1) Base: é o terminal controlador, ele que determina se haverá ou não passagem de corrente entre o coletor e o emissor.

2) Coletor: entrada do transistor, ela que inicialmente controla a tensão e corrente no emissor.

3) Emissor: saída do transistor.



Definição de Variáveis:

a) Vc: tensão no coletor;

b) Vb: tensão na base;

c) Vbe: tensão entre a base e o emissor, normalmente está entre 0,7V;

d) Ve: tensão no emissor;

Ve(max) = Vb – Vbe

Inicialmente, Ve = Vc; Mas caso, Vc < Vb: Ve = Vb – Vbe.

e) Vce = Vc – Ve;

f) Ie = Ve / Re;

g) Ic = Ie * a = Ie * ganho/ganho+1		ou	Ic = Ib * ganho

h) Ib = Ic / ganho		ou	Ib = (Vb – Vc ) / Rb

## Seções da fonte

### Papel do Transformador

No projeto da fonte vamos precisar de um transformador para reduzir a tensão da tomada, 110V ou 220V, para uma tensão entre 3V - 12V.

O papel do transformador na fonte é reduzir a tensão da entrada para que o circuito não precise trabalhar com tensões muito elevadas que podem danificar componentes ou exigir componentes mais caros.

### Papel da Ponte Retificadora



A ponte retificadora, uma associação de 4 diodos, serve para transformar a corrente alternada em uma corrente contínua pulsante (a polaridade se mantém, mas a tensão ainda varia com o tempo). A propriedade dos diodos que é utilizada na ponte retificadora é a de não conduzir quando está polarizado inversamente.

Segue uma análise da ponte retificadora em uma carga.





Note que tanto faz se o positivo está em cima e o negativo em baixo, ou o positivo em baixo e o negativo em cima. A corrente fluirá pela carga R1 no mesmo sentido: cima para baixo.



A corrente alternada passa pela ponte retificadora e se torna corrente contínua pulsante.

### Papel do Capacitor

O papel do capacitor na fonte é proporcionar o *ripple*. Como agora a corrente é contínua e pulsante, o capacitor armazena a carga e descarrega lentamente enquanto a tensão estaria abaixo da tensão que o capacitor obteve. Segue um gráfico para entender melhor o que seria o *ripple*.



No começo do primeiro ciclo da onda, o capacitor estará sendo carregado até a tensão de pico. Quando a tensão cai, o capacitor libera a carga que foi armazenada aos poucos, até que a tensão de do segundo ciclo da onda seja maior que a tensão no capacitor, que irá carregá-lo novamente. Isso se segue repetidas vezes.

Com o *ripple*, a tensão está mais estável: ainda varia, mas muito menos.

### Papel do Circuito Regulador

O circuito regulador vai regular a tensão na carga de acordo com a posição do cursor do potenciômetro.

Esse circuito será explicado por partes.

#### Divisor de tensão

O divisor de tensão nada mais é que uma análise da tensão em um resistor de um circuito de vários resistores associados em série.

O caso mais comum é o de dois resistores conectados em série. Nesse caso, a fórmula para calcular a tensão no resistor R2 é a seguinte:

    (V ∙ R2) / (R1 + R2)

Em que V é a tensão da alimentação.

A fórmula para R1 é análoga, e para divisores de tensão com mais resistores, basta considerar como R1 (ou R2) o resistor equivalente à todos os resistores exceto aquele cuja tensão está sendo analisada.

O divisor de tensão é uma consequência direta da lei das malhas de *Kirchhoff*.

#### Divisor de tensão combinado com diodo zener



Basicamente, o circuito do divisor de tensão junto com o zener é este.

Funciona da seguinte forma: se o Vout calculado pelo divisor de tensão em Rl for menos que o Vzener, então a tensão em Rl (e no zener) será Vout e a tensão em Rs será Vin - Vout.

Mas se Vout for maior que Vzener, a tensão em Rl e no zener será Vzener, e a tensão em Rs será Vin - Vzener.

Observe que o diodo zener está polarizado inversamente. Apenas dessa forma o circuito funcionará do modo esperado, pois caso contrário, seria como um diodo comum.

#### Potenciômetro, carga e transistor



A região no lado esquerdo do circuito é a do divisor de tensão combinado com o diodo zener.

Considerando apenas o divisor de tensão, o potenciômetro (de resistência Rp) pode ser considerado um resistor, conectado em série com R2.

Dessa forma, aplicando a fórmula do divisor de tensão e da resistência equivalente para resistores em série, temos:

    Vo = (V ∙ (R2 + Rp)) / (R1 + R2 + Rp)

Se Vo for maior que Vzener (o objetivo), o Vzener irá agir e, ao invés da tensão Vo passar pelo conjunto Rp e R2, será a tensão Vzener que passará.

O transistor NPN tem 2 funções principalmente: a primeira, utilizar uma corrente baixa para controlar a corrente mais alta que passará na carga (de resistência Rl); a segunda, "isolar" a carga para que ele não interfira no cálculo do divisor de tensão e altere a tensão no diodo zener.

A tensão na carga pode ser calculada como se ela estivesse em paralelo com o conjunto do resistor R2 e o potenciômetro (até onde o cursor está posicionado), considerando a queda de tensão de aproximadamente 0,7V que o transistor provoca.

É dessa forma que a tensão na carga pode ser regulada: em um dos extremos do cursor do potenciômetro, a tensão que passará pela carga será Vzener - 0,7V; no outro extremo, a tensão que passará pela carga será Vr2 (a tensão em R2) - 0,7V.

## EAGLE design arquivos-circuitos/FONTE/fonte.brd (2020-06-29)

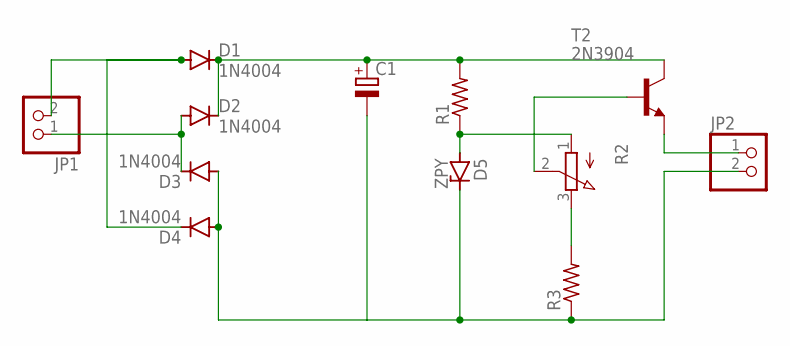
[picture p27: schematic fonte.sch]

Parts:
C1: CPOL-EUE3.5-10; E3,5-10
D1, D2, D3, D4: 1N4004; DO41-10
D5: ZPY; DO41Z10
JP1, JP2: PINHD-1X2; 1X02
R1, R3: R-US_0207/10; 0207/10
R2: 3RP/1610N
T2: 2N3904; TO92

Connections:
unnamed: D1.A, D4.C, JP1.2
unnamed: D2.A, D3.C, JP1.1
unnamed: JP2.1, T2.3 (E)
unnamed: C1.+, D1.C, D2.C, R1.2, T2.1 (C)
unnamed: D5.A, R1.1, R2.1 (A)
unnamed: R2.2 (S), T2.2 (B)
unnamed: R2.3 (E), R3.2
unnamed: C1.-, D3.A, D4.A, D5.C, JP2.2, R3.1

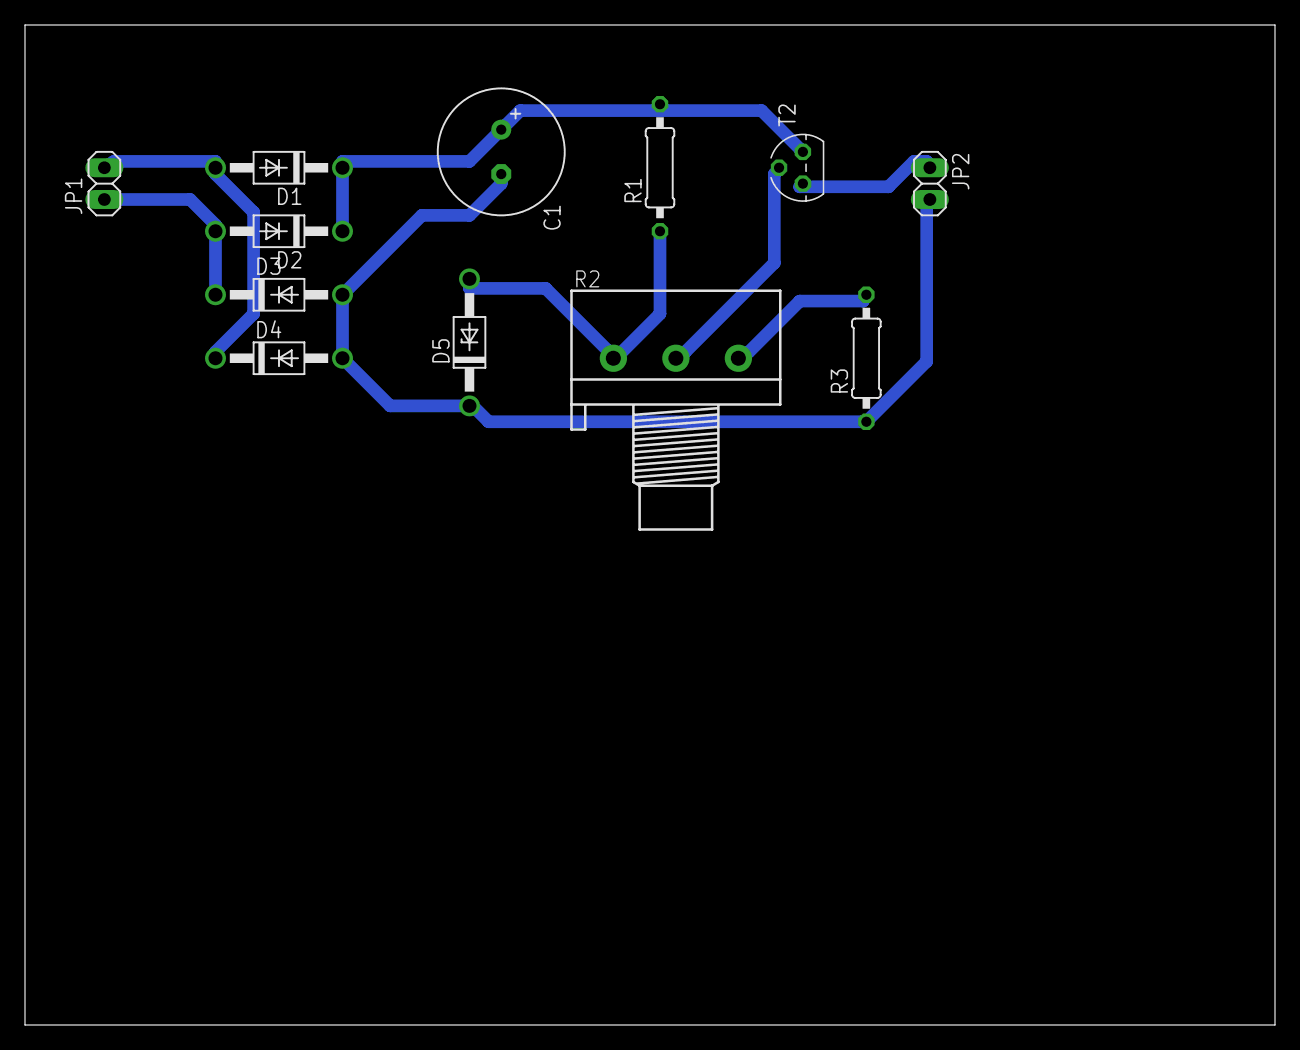
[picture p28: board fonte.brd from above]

Board: 2 copper layers, 100.0 x 80.0 mm, 12 parts (0 on the bottom side), 8 nets.

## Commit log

2020-05-26 Estudo do Projeto criado
    Adicionados tópicos resistores e capacitores
2020-06-15 Teste de markdown e imagens adicionadas
2020-06-15 Resistores em linguagem markdown
2020-06-15 Correção de erros
2020-06-15 Capacitor adicionado
2020-06-15 Correção de erros de ortografia
2020-06-17 Ponte retificadora e correção de erros de gramática
2020-06-29 Corrigindo um pulo de linha
    Corrigindo um pulo de linha no paragrafo do transformador
2020-06-29 adicionando nova imagem pro circuito
2020-06-29 adicionando no readme a foto do circuito na seção repositório
2020-06-29 Projeto Eagle
    [fonte.brd, fonte.sch]
2020-06-29 add projeto eagle
    [fonte.brd, fonte.sch]
2020-06-29 deletando arquivos sobressalentes
    [fonte.brd]
